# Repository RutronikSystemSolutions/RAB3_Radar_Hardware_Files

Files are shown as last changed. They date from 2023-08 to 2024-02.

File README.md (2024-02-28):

# RAB3-Radar Hardware Design Files

The RAB3-Radar is an evaluation board featuring the Infineon BGT60TR13CE6327XUMA1 and Nisshinbo NJR4652F2S1 60GHz Radars. 

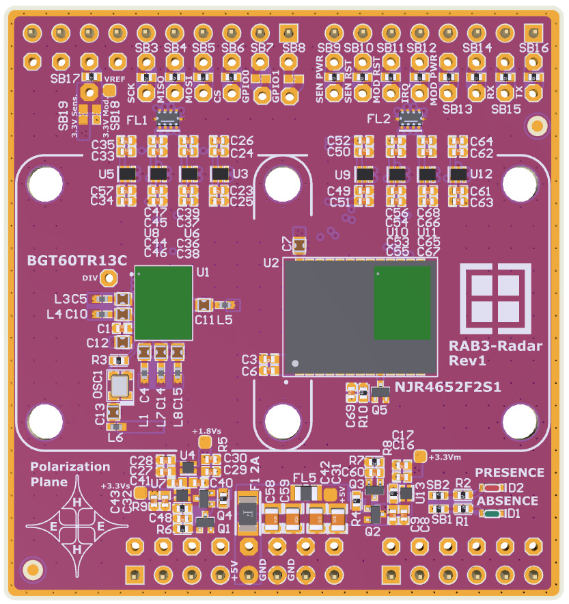
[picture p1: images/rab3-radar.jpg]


Here you may find hardware documents as follows:

- Schematics, PCB layout, and mechanical drawings
- BOM: Bill of Materials
- Assembly drawings
- Altium Designer Project
- Gerber Files

## Legal Disclaimer

The evaluation board including the software is for testing purposes only and, because it has limited functions and limited resilience, is not suitable for permanent use under real conditions. If the evaluation board is nevertheless used under real conditions, this is done at one’s responsibility; any liability of Rutronik is insofar excluded. 

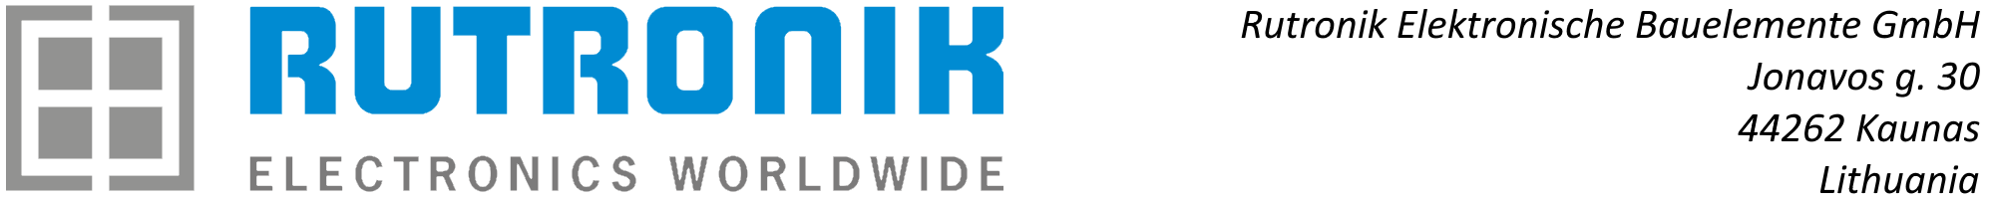
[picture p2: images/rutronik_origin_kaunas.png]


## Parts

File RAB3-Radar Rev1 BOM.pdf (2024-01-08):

Part Description | Specification | Value | Designator | Footprint | Quantity | Manufacturer | Manufacturer Part No. | Supplier | Supplier part number
Ceramic Capacitor | X5R, 6.3V, 10% | 1uF | C1, C8, C27, C40 | C0402 | 4 | Samsung EM | CL05A105KQ5NNNC | Rutronik | KKK18264
Ceramic Capacitor | X5R, 6.3V, 20% | 10uF | C3, C16, C29, C32 | C0402 | 4 | Samsung EM | CL05A106MQ5NUNC | Rutronik | KKS2215
Feed Through Capacitor | 4V, 2A, 20% | 22uF | C4, C5, C7, C10, C11, C12, C13, C14, C15 | NFMJMPC226R0G3D | 9 | muRata | NFMJMPC226R0G3D | Rutronik | NFMJMPC226R0G3D
Ceramic Capacitor | NP0, 50V, 5% | 33pF | C6, C9, C17, C23, C24, C28, C30, C33, C36, C37, C41, C43, C44, C45, C48, C49, C50, C53, C54, C57, C60, C61, C62, C65, C66, C69 | C0402 | 26 | AVX | 04025A330JAT2A | Rutronik | KKK13594
Ceramic Capacitor | X7R, 50V, 10% | 100nF | C25, C26, C34, C35, C38, C39, C46, C47, C51, C52, C55, C56, C63, C64, C67, C68 | C0402 | 16 | Yageo | CC0402KRX7R9BB104 | Rutronik | KKK23619
Ceramic Capacitor | X7R, 50V, 10% | 1uF | C31 | C0805 | 1 | Yageo | CC0805KKX7R9BB105 | Rutronik | KKK20733
Ceramic Capacitor | X7R, 25V, 20% | 22uF | C42 | C0805 | 1 | Samsung EM | CL21A226MAYNNNE | Rutronik | KKK24951
Ceramic Capacitor | X7R, 50V, 10% | 10nF | C58 | C0805 | 1 | Yageo | CC0805KRX7R9BB103 | Rutronik | KKK13596
Ceramic Capacitor | X7R, 50V, 10% | 100nF | C59 | C0805 | 1 | Yageo | CC0805KRX7R9BB104 | Rutronik | KKK15320
TOPLED® E1608 | GREEN, 20mA | KGDELLS1.22-JGKH-24-0-2-S | D1 | KG_DELLS_GREEN | 1 | OSRAM | KGDELLS1.22-JGKH-24-0-2-S | Rutronik | LEDATV1791
TOPLED® E1608 | RED, 20mA | KSDELLS1.22-JHKI-1-0-2-S | D2 | KS_DELLS_RED | 1 | OSRAM | KSDELLS1.22-JHKI-1-0-2-S | Rutronik | LEDATV2344
High I²t Chip fuse | 32V, 2A | CC12H2A-TR | F1 | FUSE1206 | 1 | EATON | CC12H2A-TR | Rutronik | FUSE10755
EMI Suppression LC Filter | 50MHz . 20mA | NFA21SL806X1A48L | FL1, FL2 | NFA21SL506X1A48L | 2 | muRata | NFA21SL806X1A48L | Rutronik | FE3998
Ferrite Bead | 1K@100MHz, 1.5A | MPZ2012S102AT000 | FL5 | Inductor_BKPA00201210 | 1 | TDK Corporation | MPZ2012S102AT000 | Rutronik | FE2928
Ferrite Bead | 600Ohm, 0.23A | BLM15PX601SN1D | L1, L3, L4, L5, L6, L7, L8 | L0402 | 7 | muRata | BLM15PX601SN1D | Rutronik | FE4904
Clock Oscillator | 80 MHz, ±50ppm | 80 MHz | OSC1 | OSC2016 | 1 | Kyocera AVX | KC2016K80.0000C1GE00 | Rutronik | KC2016K80.0000C1GE00
Arduino Connector | 10 pos. 2,54mm | SL 20 THR 124 10 Z | P1 | HDR1X10_ARDUINO | 1 | Fischer Elektronik | SL 20 THR 124 10 Z | Rutronik | SL 20 THR 124 10 Z
Arduino Connector | 8 pos. 2,54mm | SL 20 THR 124 8 Z | P3, P5 | HDR1X8_ARDUINO | 2 | Fischer Elektronik | SL 20 THR 124 8 Z | Rutronik | SL 20 THR 124 8 Z
Arduino Connector | 6 pos. 2,54mm | SL 20 THR 124 6 Z | P4 | HDR1X6_ARDUINO | 1 | Fischer Elektronik | SL 20 THR 124 6 Z | Rutronik | SL 20 THR 124 6 Z
N-Channel MOSFET | 20V, 0.63A | DMG1012T-7 | Q1, Q3, Q5 | SOT-523_custom | 3 | Diodes Inc. | DMG1012T-7 | Rutronik | TMOSS6623
P-Channel MOSFET | -20V, -0.6A | PJE8403_R1_00001 | Q2, Q4 | SOT-523_custom | 2 | PANJIT | PJE8403_R1_00001 | Rutronik | TMOS2833
Thick Film Resistor | 5% 0,063W | 220R | R1, R2 | R0402 | 2 | Yageo | RC0402JR-13220RL | Rutronik | WRC54705
Thick Film Resistor | 5% 0,063W | 150R | R3 | R0402 | 1 | Yageo | RC0402JR-07150RL | Rutronik | WRC33815
Thick Film Resistor | 1% 0,063W | 49.9K | R4, R5, R6, R7, R8, R9, R10 | R0402 | 7 | Yageo | RC0402FR-0749K9L | Rutronik | WRC34049
Thick Film Resistor | 5% 0,063W | 0R | SB1, SB2, SB3, SB4, SB5, SB6, SB9, SB10, SB11, SB12, SB13, SB14, SB15, SB16, SB17 | SB_0402 | 15 | Yageo | RC0402JR-070RL | Rutronik | WRC34031
60 GHz Radar Sensor | 57GHz ~ 64GHz, 3.3V | BGT60TR13CE6327XUMA1 | U1 | PG-VF2BGA-40-1 | 1 | Infineon Technologies BGT60TR13CE6327XUMA1 | | Rutronik | BGT60TR13CE6327XUMA1
60GHz Smart Sensor Micro-Module | 57GHz ~ 64GHz, 5.5V | NJR4652F2S1 | U2 | NJR4652 | 1 | NISSHINBO | NJR4652F2S1 | Rutronik | NJR4652F2S1
Single Bit Voltage Level Translator | 5.5V, 1.65V | 74LVC1T45FZ4-7 | U3, U5, U6, U8, U9, U10, U11, U12 | X2-DFN1410-6 | 8 | Diodes Inc. | 74LVC1T45FZ4-7 | Rutronik | ICLOG10841
250mA High PSRR Low Noise LDO with Enable | 5.5V, 1.8V, 250mA | AP7353-18FS4-7 | U4 | X2-DFN1010-4 | 1 | Diodes Inc. | AP7353-18FS4-7 | Rutronik | AP7353-18FS4-7
150mA Ultra-Low Quiescent Current LDO with Enable | 5.5V,3.3V, 150mA | AP7354-33FS4-7 | U7, U13 | X2-DFN1010-4 | 2 | Diodes Inc. | AP7354-33FS4-7 | Rutronik | ICSPR10461

### RAB3-Radar Rev1 BOM

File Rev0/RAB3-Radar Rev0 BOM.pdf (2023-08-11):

Part Description | Specification | Value | Designator | Footprint | Quantity | Manufacturer | Manufacturer Part No. | Supplier | Supplier part number
Ceramic Capacitor | X5R, 6.3V, 10% | 1uF | C1, C5, C8, C11, C16, C17, C18, C20, C21, C22, C27, C29, C40, C42 | C0402 | 14 | Samsung EM | CL05A105KQ5NNNC | Rutronik | KKK18264
Ceramic Capacitor | NP0, 50V, 5% | 33pF | C2, C6, C23, C24, C28, C30, C33, C36, C37, C41, C43, C44, C45, C48, C49, C50, C53, C54, C57 | C0402 | 19 | AVX | 04025A330JAT2A | Rutronik | KKK13594
Ceramic Capacitor | X5R, 6.3V, 20% | 10uF | C3, C4, C7, C10, C13, C14, C15 | C0402 | 7 | Samsung EM | CL05A106MQ5NUNC | Rutronik | KKS2215
Ceramic Capacitor | X7R, 50V, 10% | 100nF | C9, C12, C25, C26, C34, C35, C38, C39, C46, C47, C51, C52, C55, C56 | C0402 | 14 | Yageo | CC0402KRX7R9BB104 | Rutronik | KKK23619
Ceramic Capacitor | X7R, 25V, 10% | 4.7nF | C19 | C0402 | 1 | KEMET | C0402C472K3RAC7867 | Rutronik | KKK26721
Niobium Oxide Capacitor | 6.3V, 20% | 47uF | C31, C32 | Case-B | 2 | AVX | NOJB476M006RWJ | Rutronik | KTA6684
TOPLED® E1608 | GREEN, 20mA | KGDELLS1.22-JGKH-24-0-2-S | D1 | KG_DELLS_GREEN | 1 | OSRAM | KGDELLS1.22-JGKH-24-0-2-S | Rutronik | LEDATV1791
TOPLED® E1608 | RED, 20mA | KSDELLS1.22-JHKI-1-0-2-S | D2 | KS_DELLS_RED | 1 | OSRAM | KSDELLS1.22-JHKI-1-0-2-S | Rutronik | LEDATV2344
High I²t Chip fuse | 32V, 2A | CC12H2A-TR | F1 | FUSE1206 | 1 | EATON | CC12H2A-TR | Rutronik | FUSE10755
Ferrite Bead | 600Ohm, 0.23A | BLM15PX601SN1D | L1, L2, L3, L4, L5, L6, L7, L8 | L0402 | 8 | muRata | BLM15PX601SN1D | Rutronik | FE4904
Clock Oscillator | 80 MHz, ±20ppm | 80 MHz | OSC1 | OSC2016 | 1 | Kyocera AVX | KC2016Z80.0000C1KX00 | Rutronik | KC2016Z80.0000C1KX00
Arduino Connector | 10 pos. 2,54mm | AW140-EG-G10B | P1 | HDR1X10_ARDUINO | 1 | ASSMANN WSW | AW140-EG-G10B | Rutronik | AW140-EG-G10B
Arduino Connector | 8 pos. 2,54mm | AW140-EG-G08B | P3, P5 | HDR1X8_ARDUINO | 2 | ASSMANN WSW | AW140-EG-G08B | Rutronik | AW140-EG-G08B
Arduino Connector | 6 pos. 2,54mm | AW140-EG-G06B | P4 | HDR1X6_ARDUINO | 1 | ASSMANN WSW | AW140-EG-G06B | Rutronik | AW140-EG-G06B
N-Channel MOSFET | 20V, 0.63A | DMG1012T-7 | Q1 | SOT-523_custom | 1 | Diodes Inc. | DMG1012T-7 | Rutronik | TMOSS6623
Thick Film Resistor | 5% 0,063W | 220R | R1, R2 | R0402 | 2 | Yageo | RC0402JR-13220RL | Rutronik | WRC54705
Thick Film Resistor | 5% 0,063W | 150R | R3 | R0402 | 1 | Yageo | RC0402JR-07150RL | Rutronik | WRC33815
Thick Film Resistor | 1% 0,063W | 49.9K | R5, R6 | R0402 | 2 | Yageo | RC0402FR-0749K9L | Rutronik | WRC34049
Thick Film Resistor | 5% 0,063W | 0R | SB1, SB2, SB3, SB4, SB5, SB6, SB7, SB8, SB9, SB10, SB11, SB12, SB13, SB14, SB15, SB16 | SB_0402 | 16 | Yageo | RC0402JR-070RL | Rutronik | WRC34031
60 GHz Radar Sensor | 57GHz ~ 64GHz, 3.3V | BGT60TR13CE6327XUMA1 | U1 | PG-VF2BGA-40-1 | 1 | Infineon Technologies | BGT60TR13CE6327XUMA1 | Rutronik | BGT60TR13CE6327XUMA1
60GHz Smart Sensor Micro-Module | 57GHz ~ 64GHz, 5.5V | NJR4652F2S1 | U2 | NJR4652 | 1 | NISSHINBO | NJR4652F2S1 | Rutronik | NJR4652F2S1
Single Bit Voltage Level Translator | 3.6V, 1.2V | 74AVC1T45FZ4-7 | U3, U5, U6, U8, U9, U10 | X2-DFN1410-6 | 6 | Diodes Inc. | 74AVC1T45FZ4-7 | Rutronik | 74AVC1T45FZ4-7
250mA High PSRR Low Noise LDO with Enable | 5.5V, 1.8V, 250mA | AP7353-18FS4-7 | U4 | X2-DFN1010-4 | 1 | Diodes Inc. | AP7353-18FS4-7 | Rutronik | AP7353-18FS4-7
150mA Ultra-Low Quiescent Current LDO with Enable | 5.5V,3.3V, 150mA | AP7354-33FS4-7 | U7 | X2-DFN1010-4 | 1 | Diodes Inc. | AP7354-33FS4-7 | Rutronik | ICSPR10461

## RAB3-Radar Rev0 BOM

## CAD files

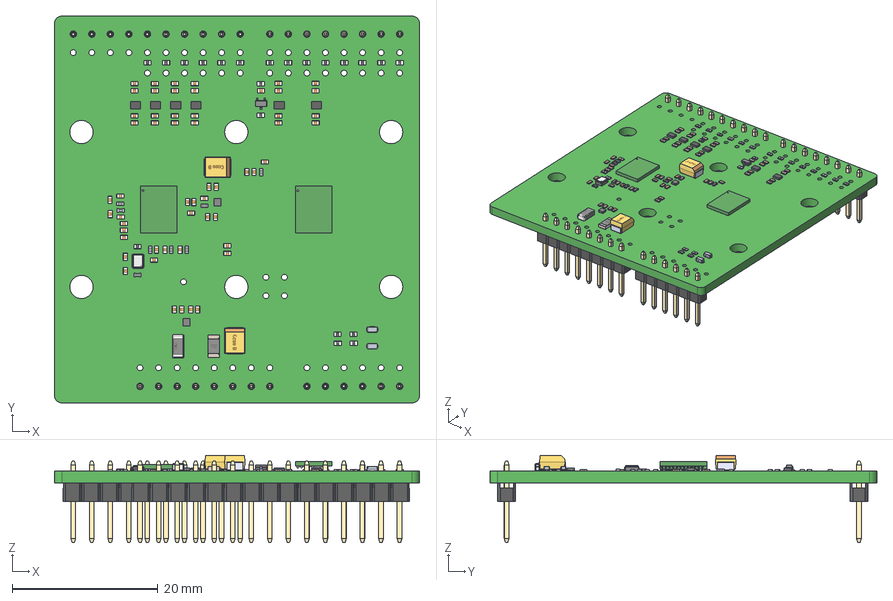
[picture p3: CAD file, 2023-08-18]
Rev0/RAB3-Radar Step Model.step
50.0 x 53.0 x 12.0 mm
Extruded x 6
LDF x 2
PG-VF2BGA-40-1 x 2
User_Library-SOT-523
pin_header_aw140-eg-g08d x 2
pin_header_aw140-eg-g06d
pin_header_aw140-eg-g10d
2016_osc
inductor_0402 x 8
User_Library-SF-1206F
KG_DELMS1_22_20160429_geometry x 2
SW3dPS-0402_SMD_Capacitor x 55
User_Library-Tantalum_Capacitor_Case_B_Tantalum_case_B_part1 x 2
User_Library-Tantalum_Capacitor_Case_B_Tantalum_case_B_part2 x 4

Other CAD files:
RAB3-Radar Parasolid Model.x_t

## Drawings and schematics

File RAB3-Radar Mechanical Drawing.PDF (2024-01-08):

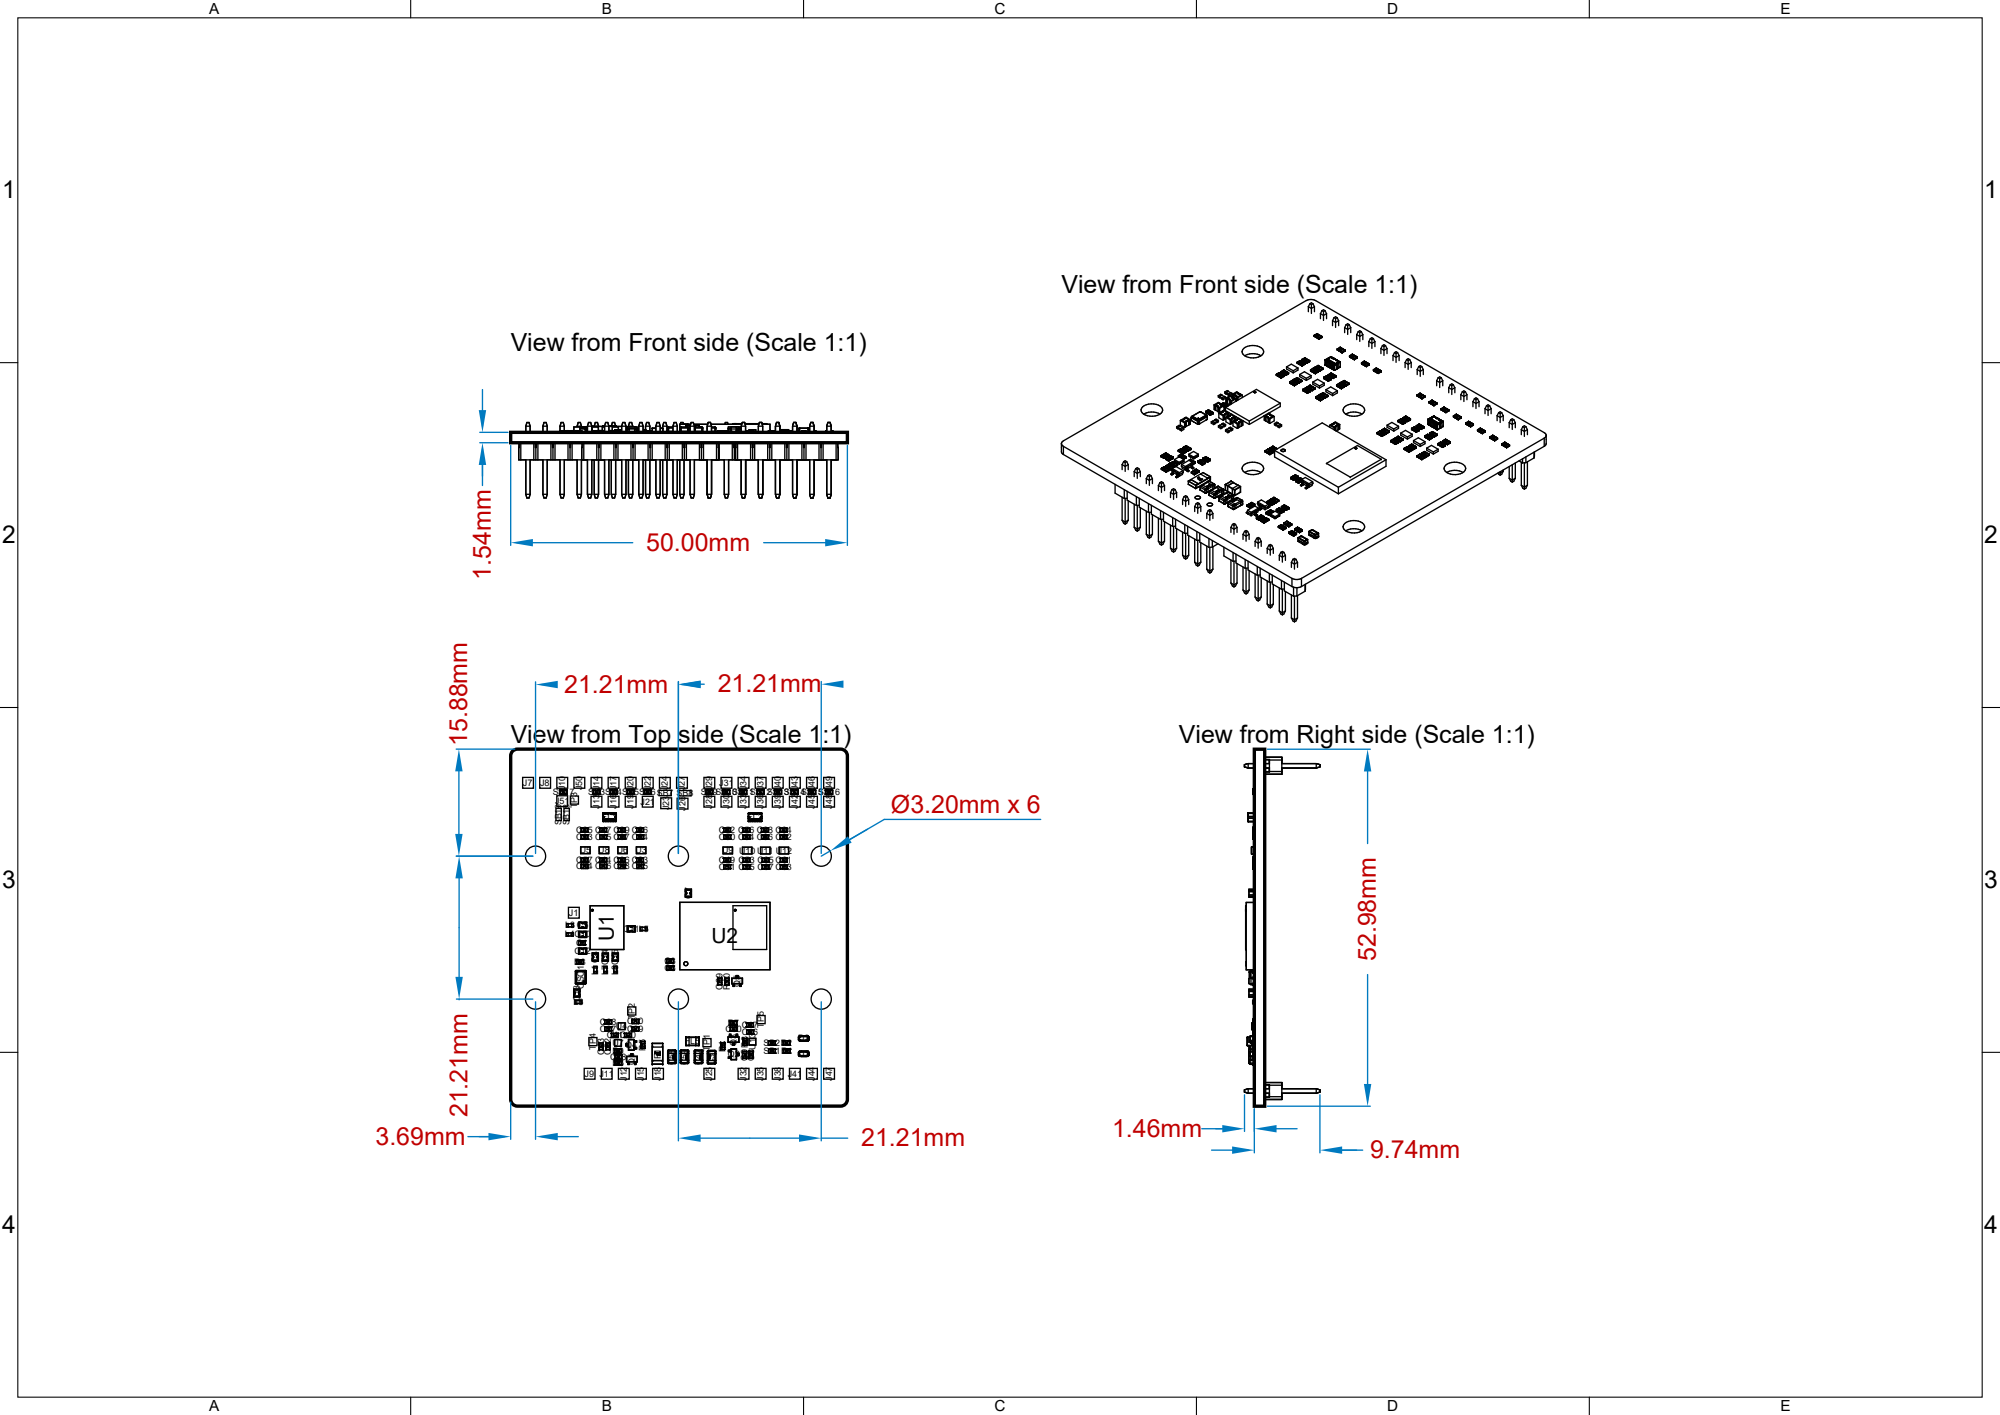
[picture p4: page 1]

View from Front side (Scale 1:1) 52.98mm

View from Front side (Scale 1:1)

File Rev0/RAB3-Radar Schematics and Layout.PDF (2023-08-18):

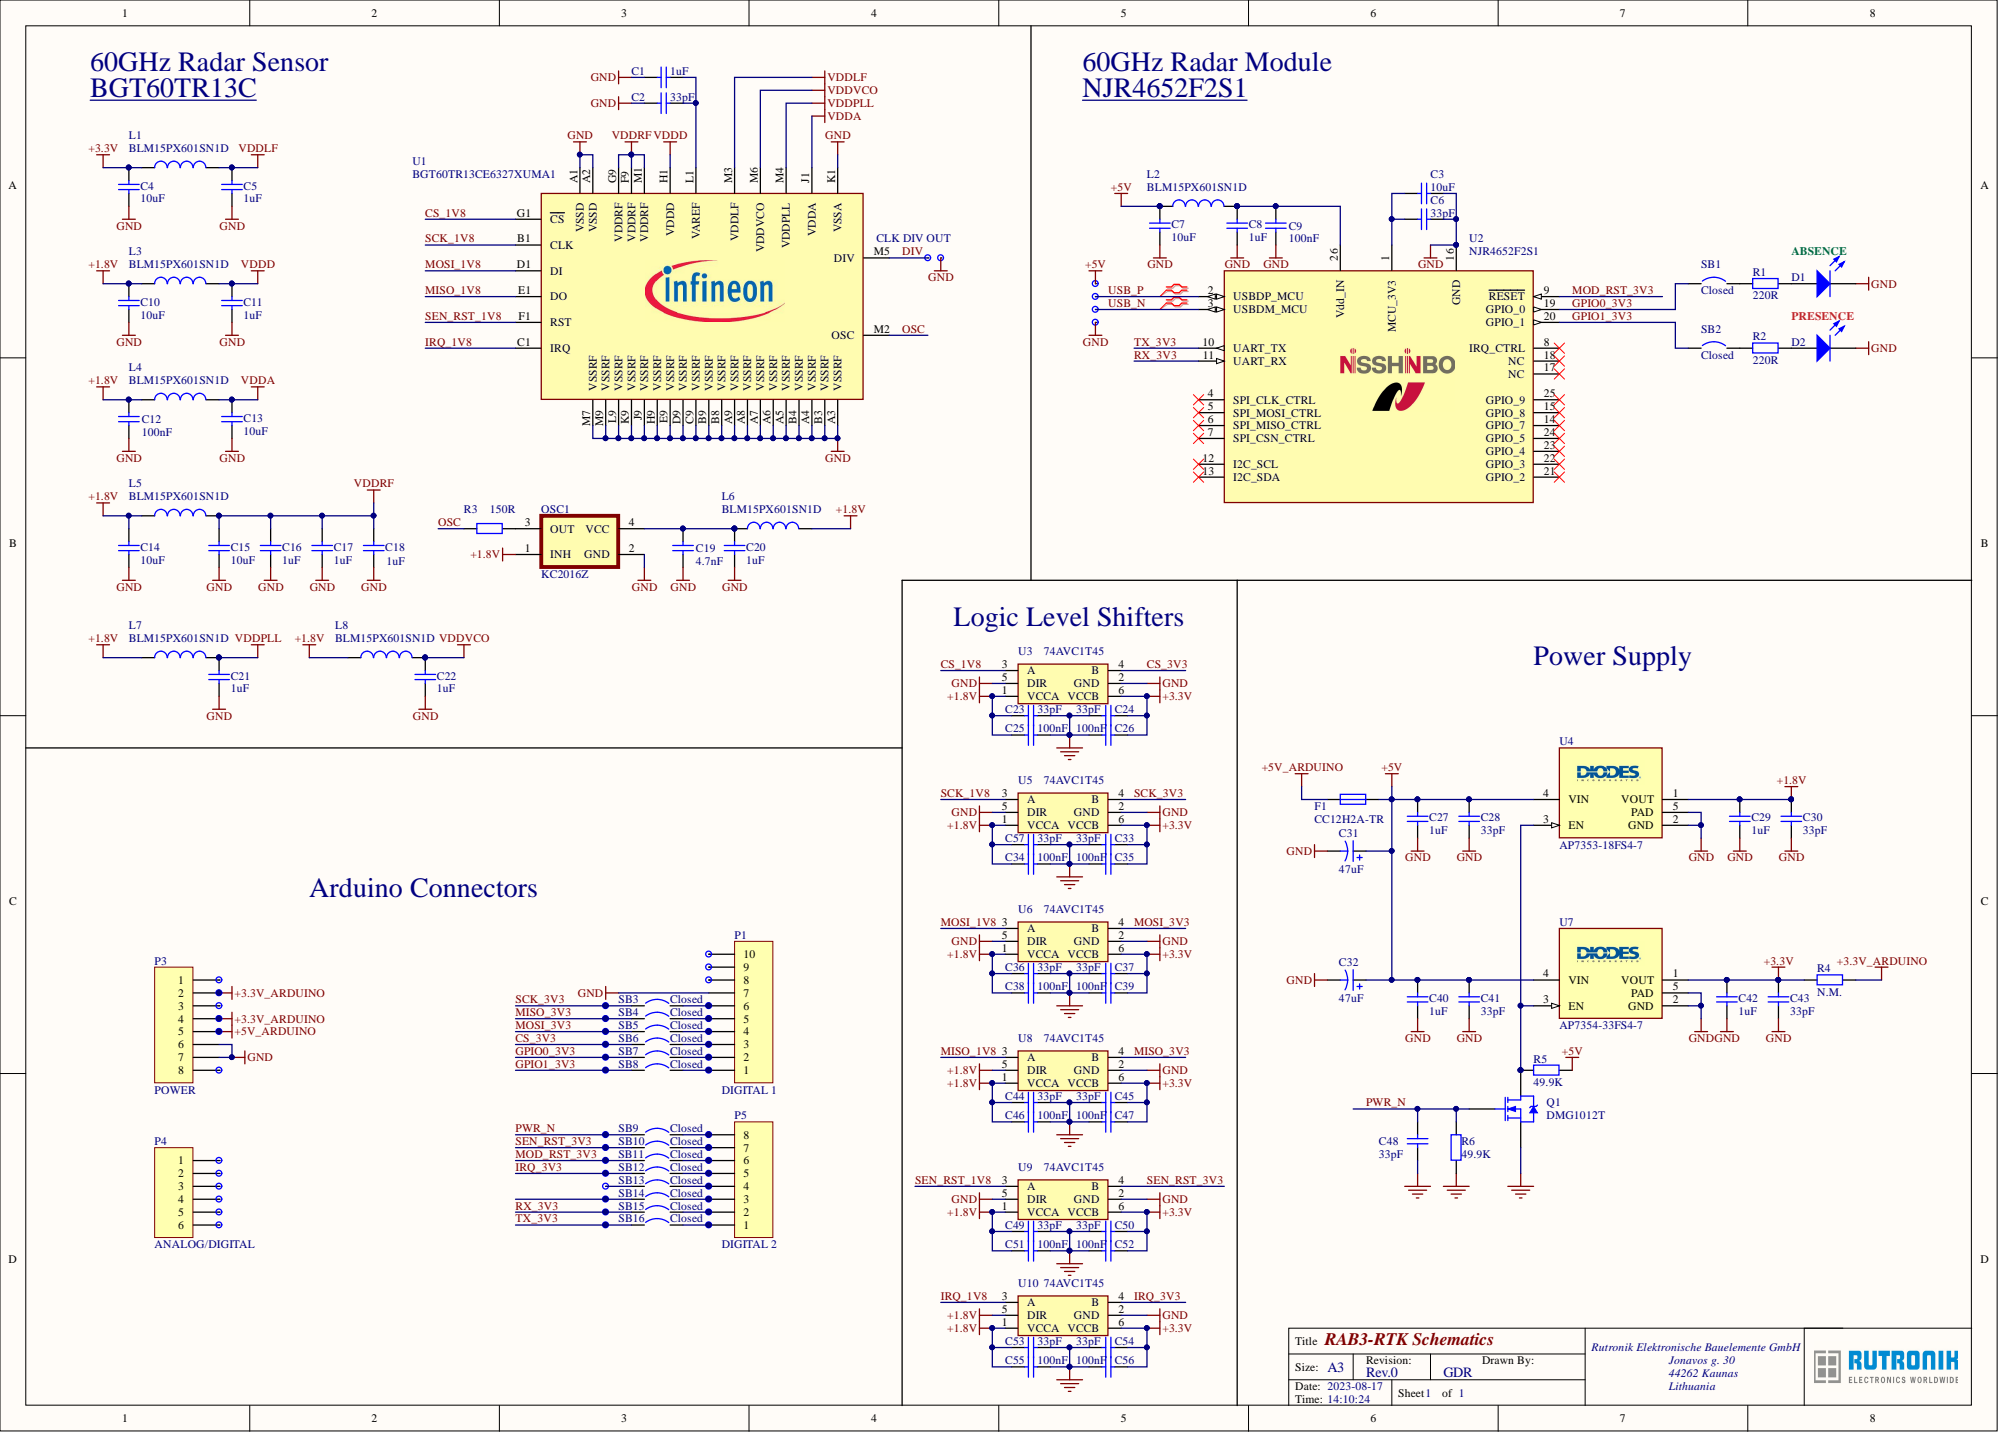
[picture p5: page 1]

VSSRF H9 VSSRF J9 VSSRF K9 VSSRF L9 VSSRF M9

VSSRF A5 VSSRF A6 VSSRF A7 VSSRF A8 VSSRF A9

Title RAB3-RTK Schematics | Rutronik Elektronische Bauelemente GmbH Jonavos g. 30 44262 Kaunas

A3 Size: | Revision: | Drawn By: GDR

Date: 14:10:24 | Sheet 1 of Time: | Lithuania 1

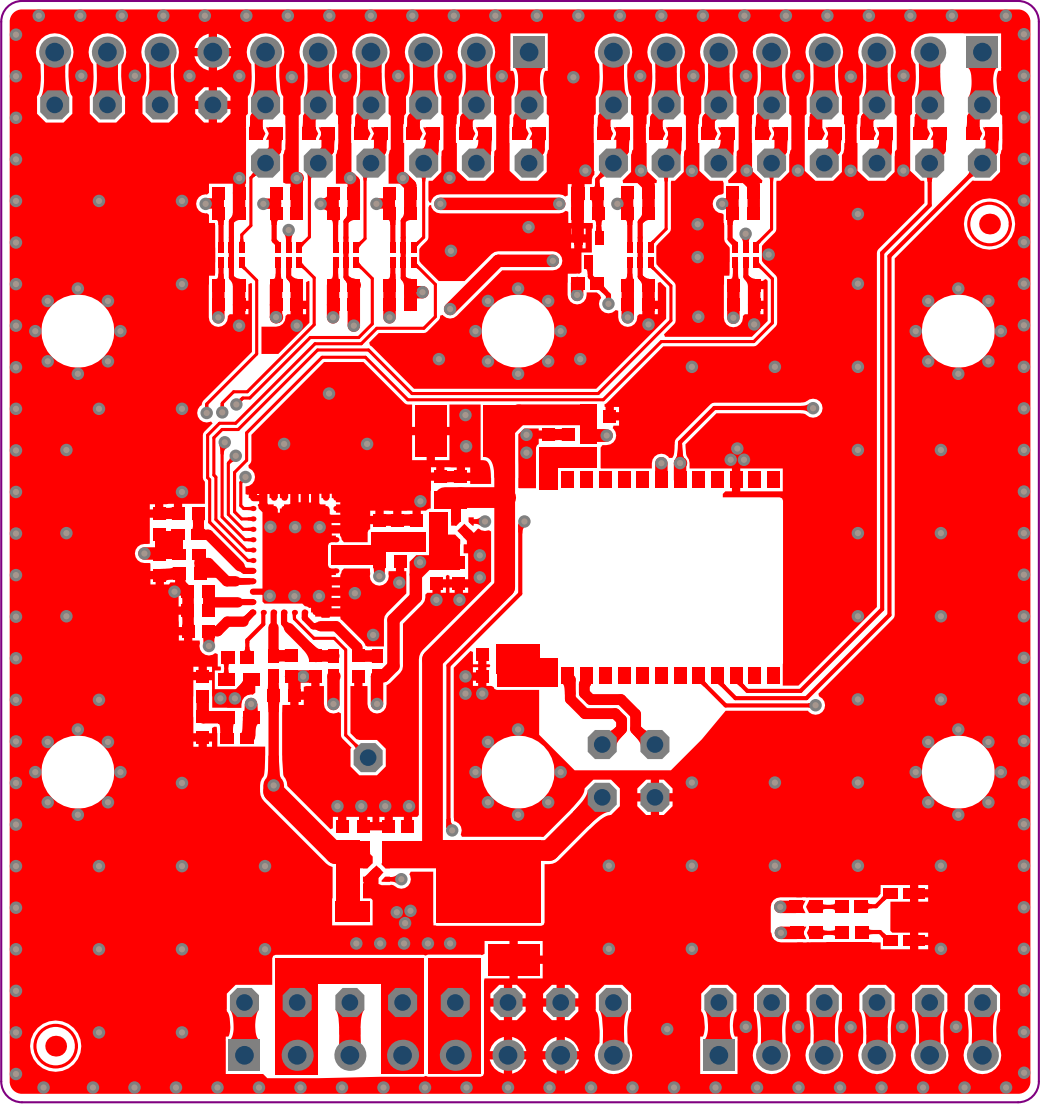
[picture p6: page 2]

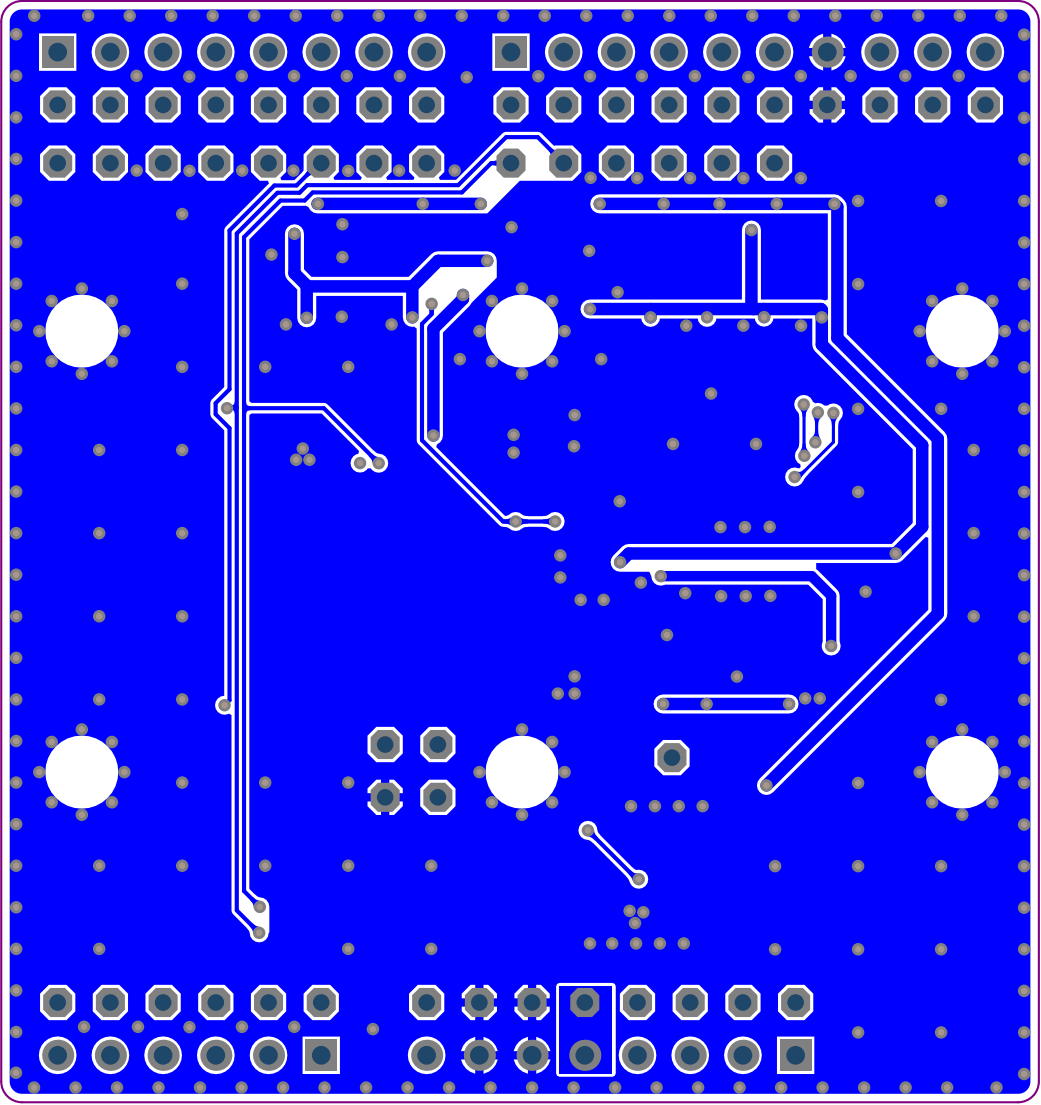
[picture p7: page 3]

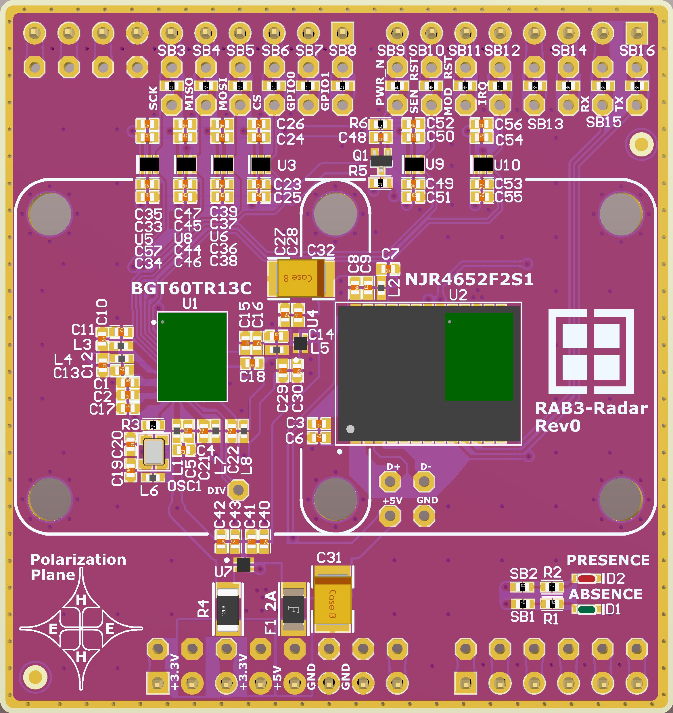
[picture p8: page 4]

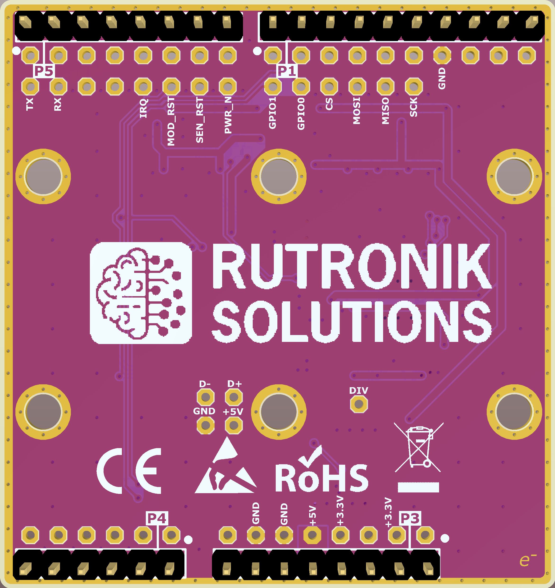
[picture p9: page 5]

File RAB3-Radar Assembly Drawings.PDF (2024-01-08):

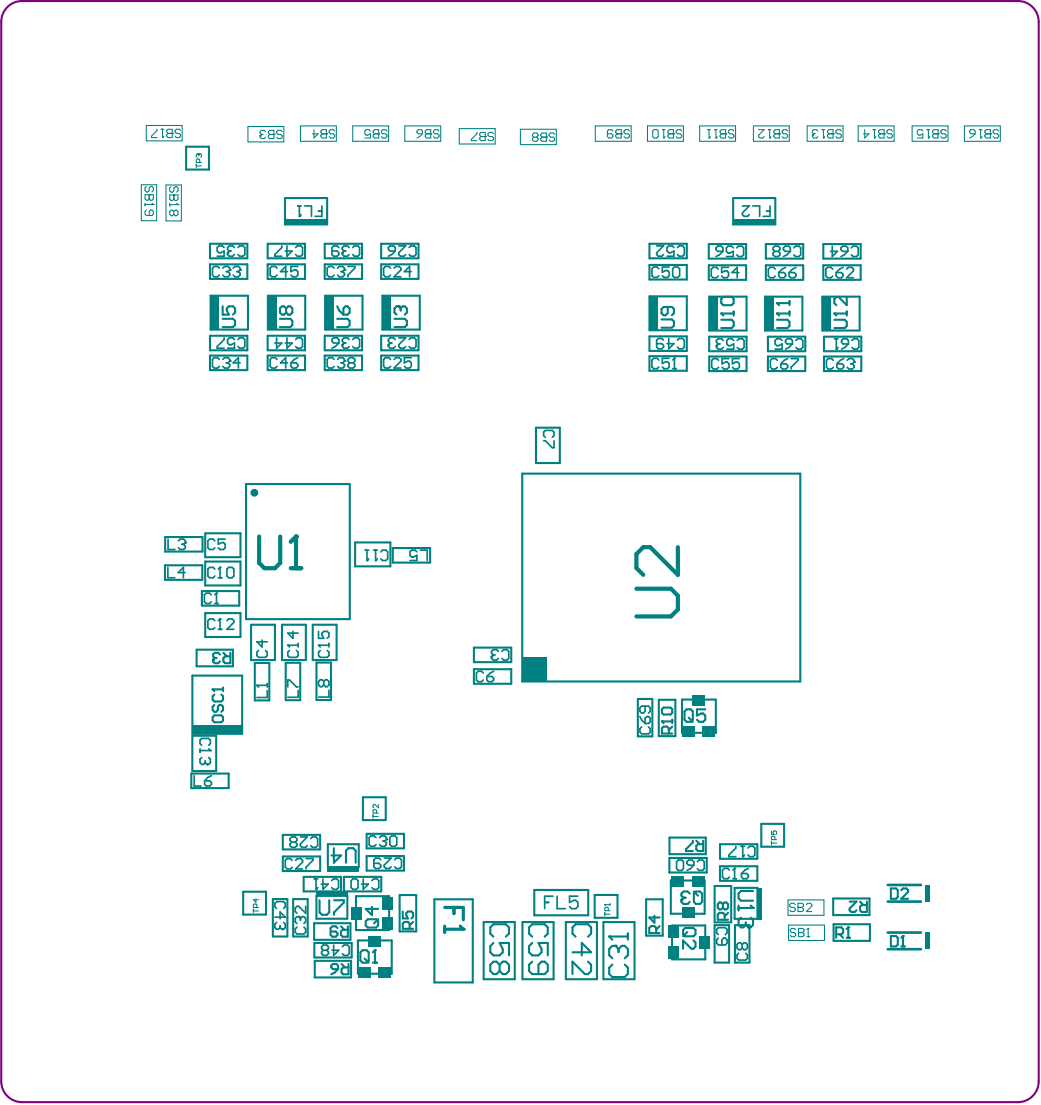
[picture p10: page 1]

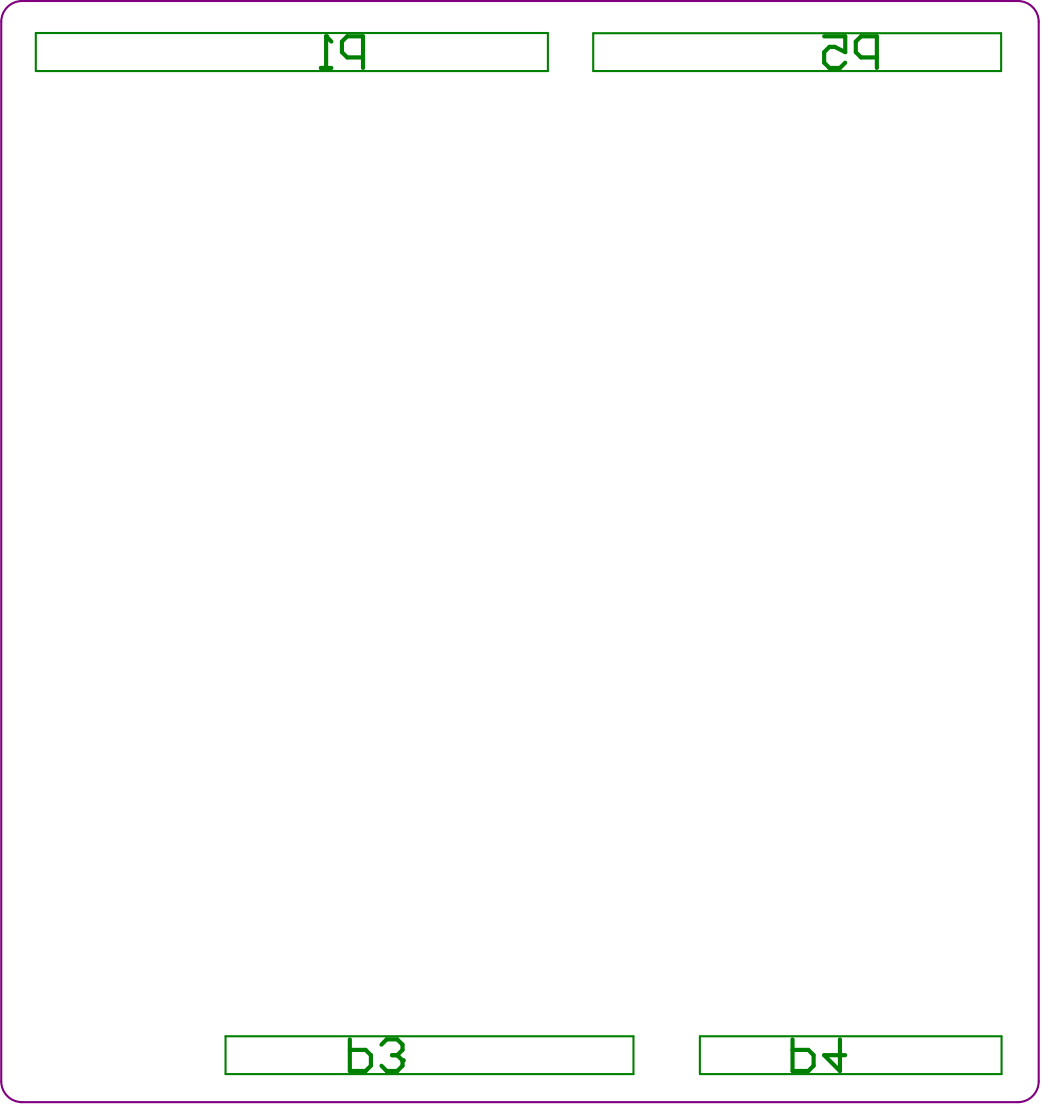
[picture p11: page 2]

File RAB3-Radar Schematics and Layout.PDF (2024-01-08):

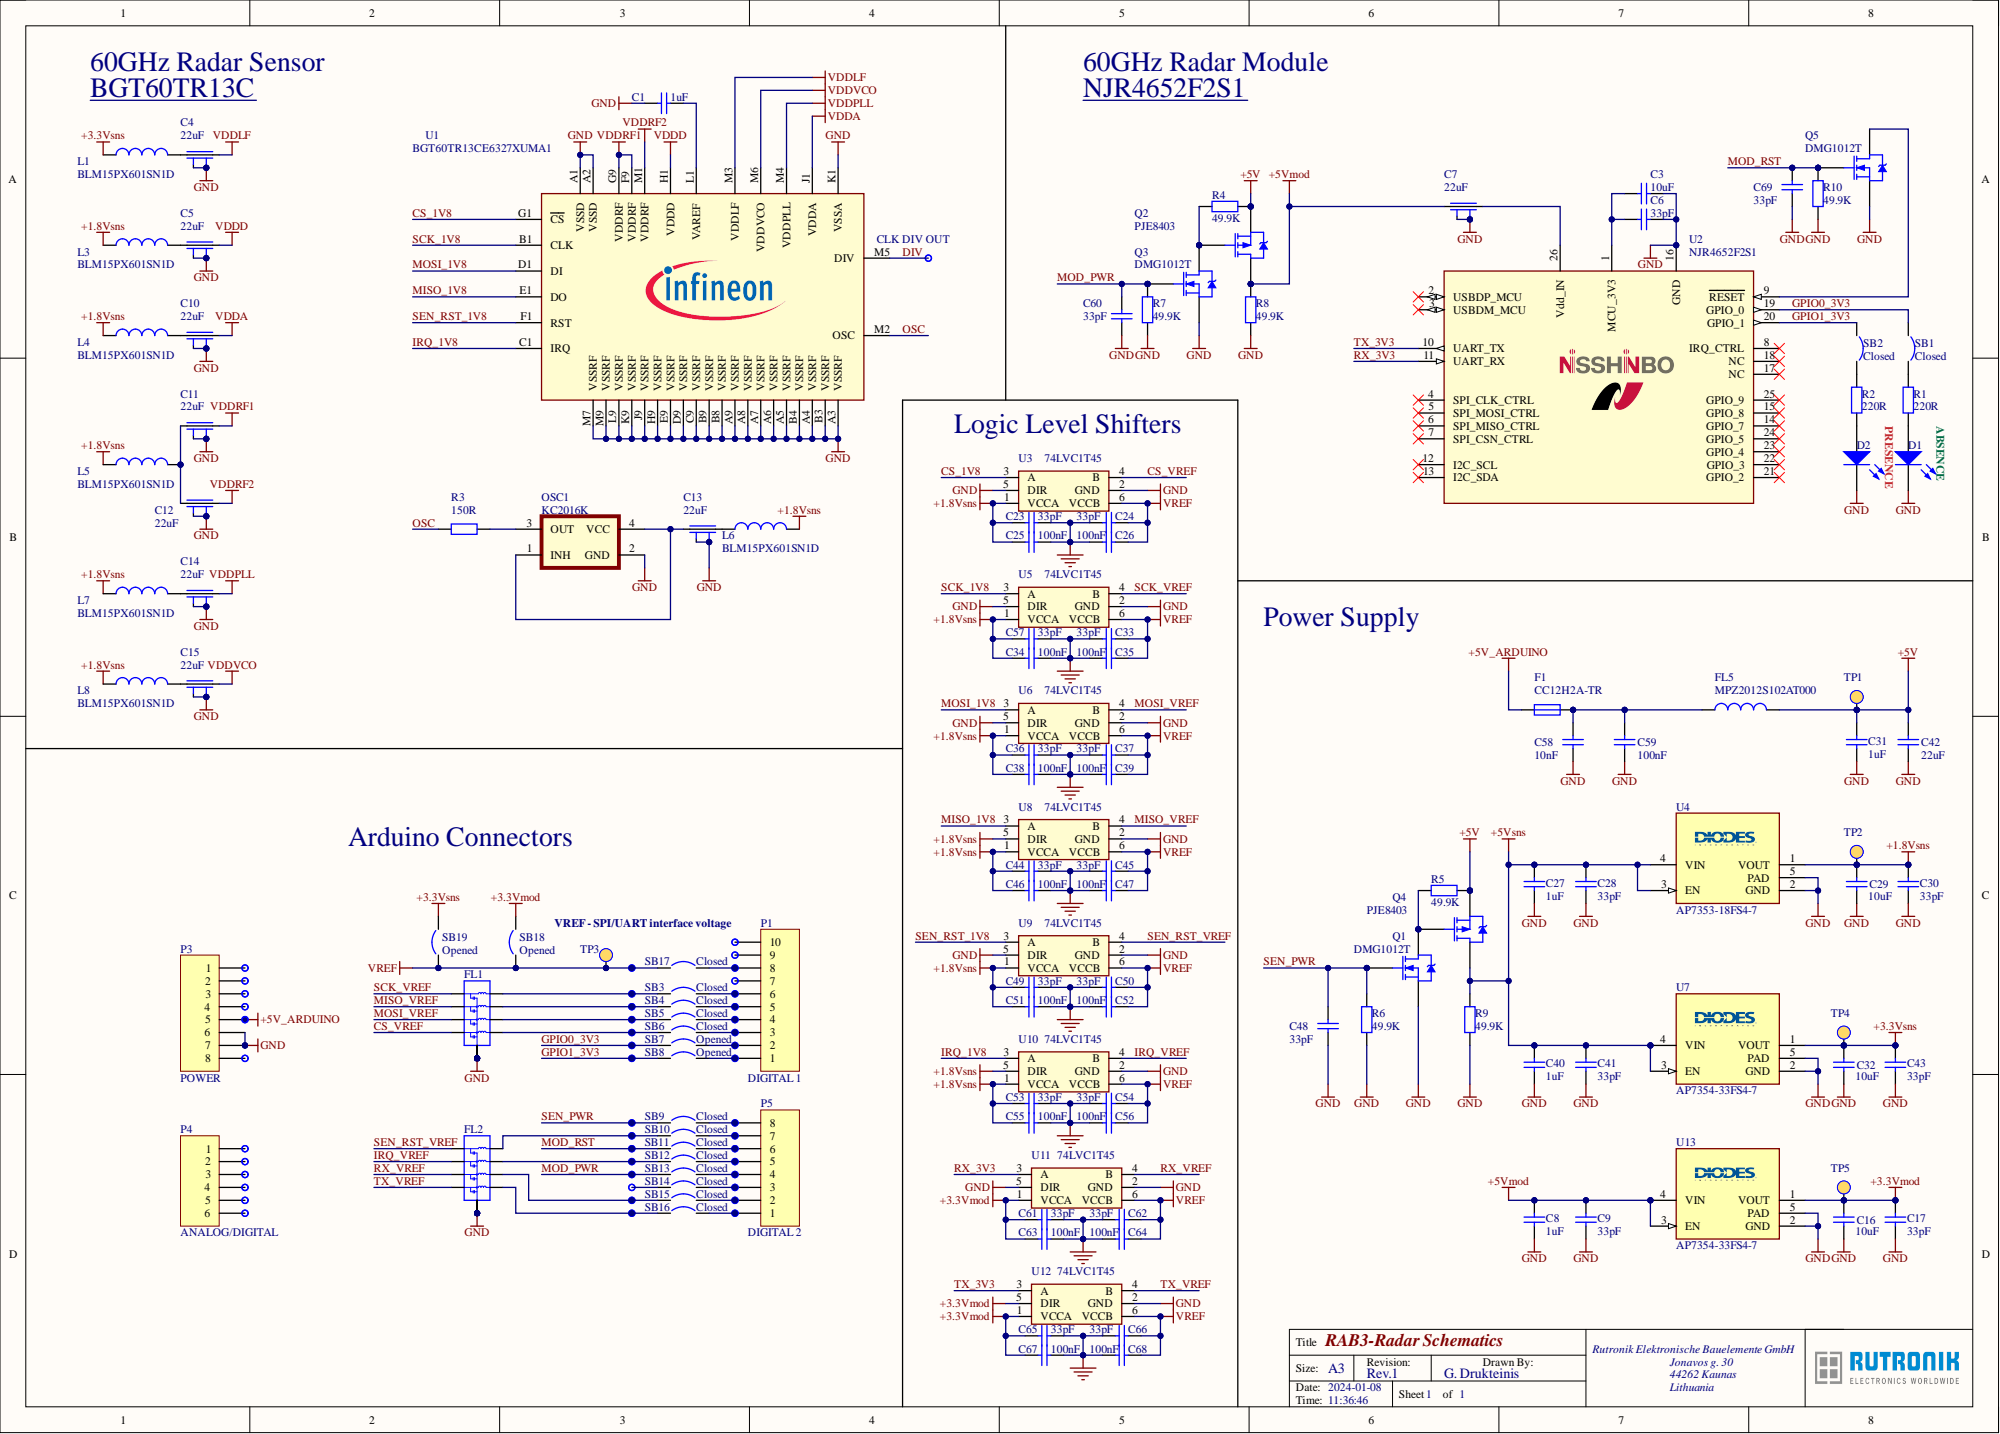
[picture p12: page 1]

VSSRF H9 VSSRF J9 VSSRF K9 VSSRF L9 VSSRF M9

VSSRF A5 VSSRF A6 VSSRF A7 VSSRF A8 VSSRF A9

Size : A 3 | Rev i s i o n : Re v . 1 | Draw n By : G. Dru ktein i s

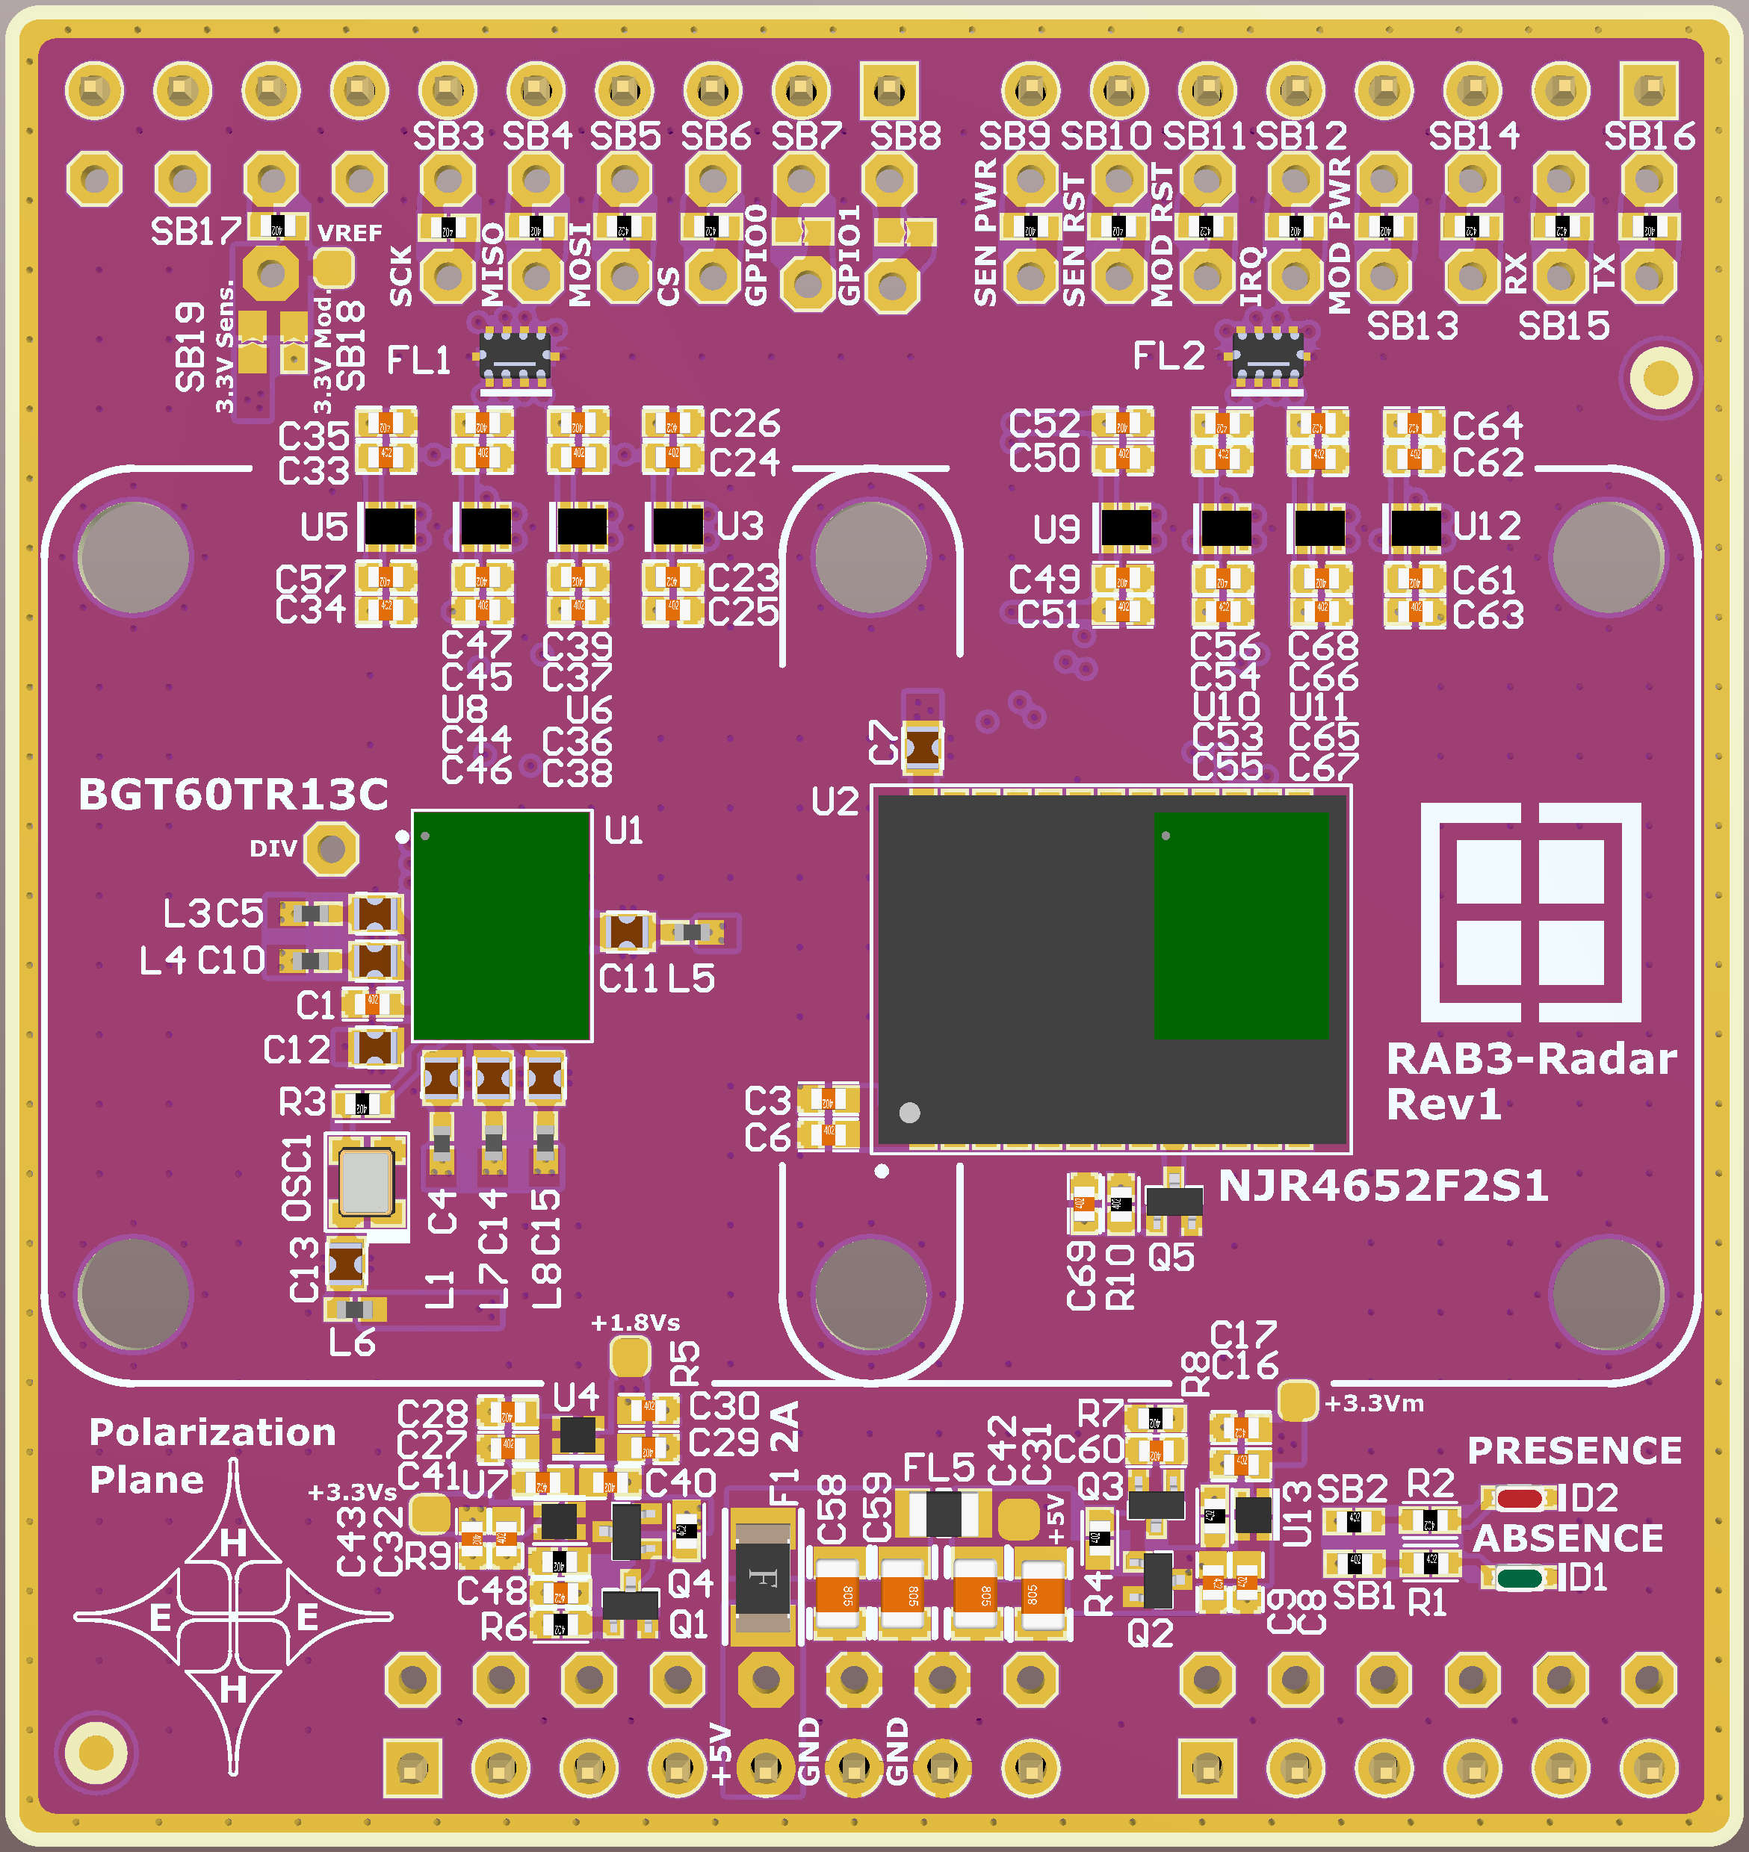
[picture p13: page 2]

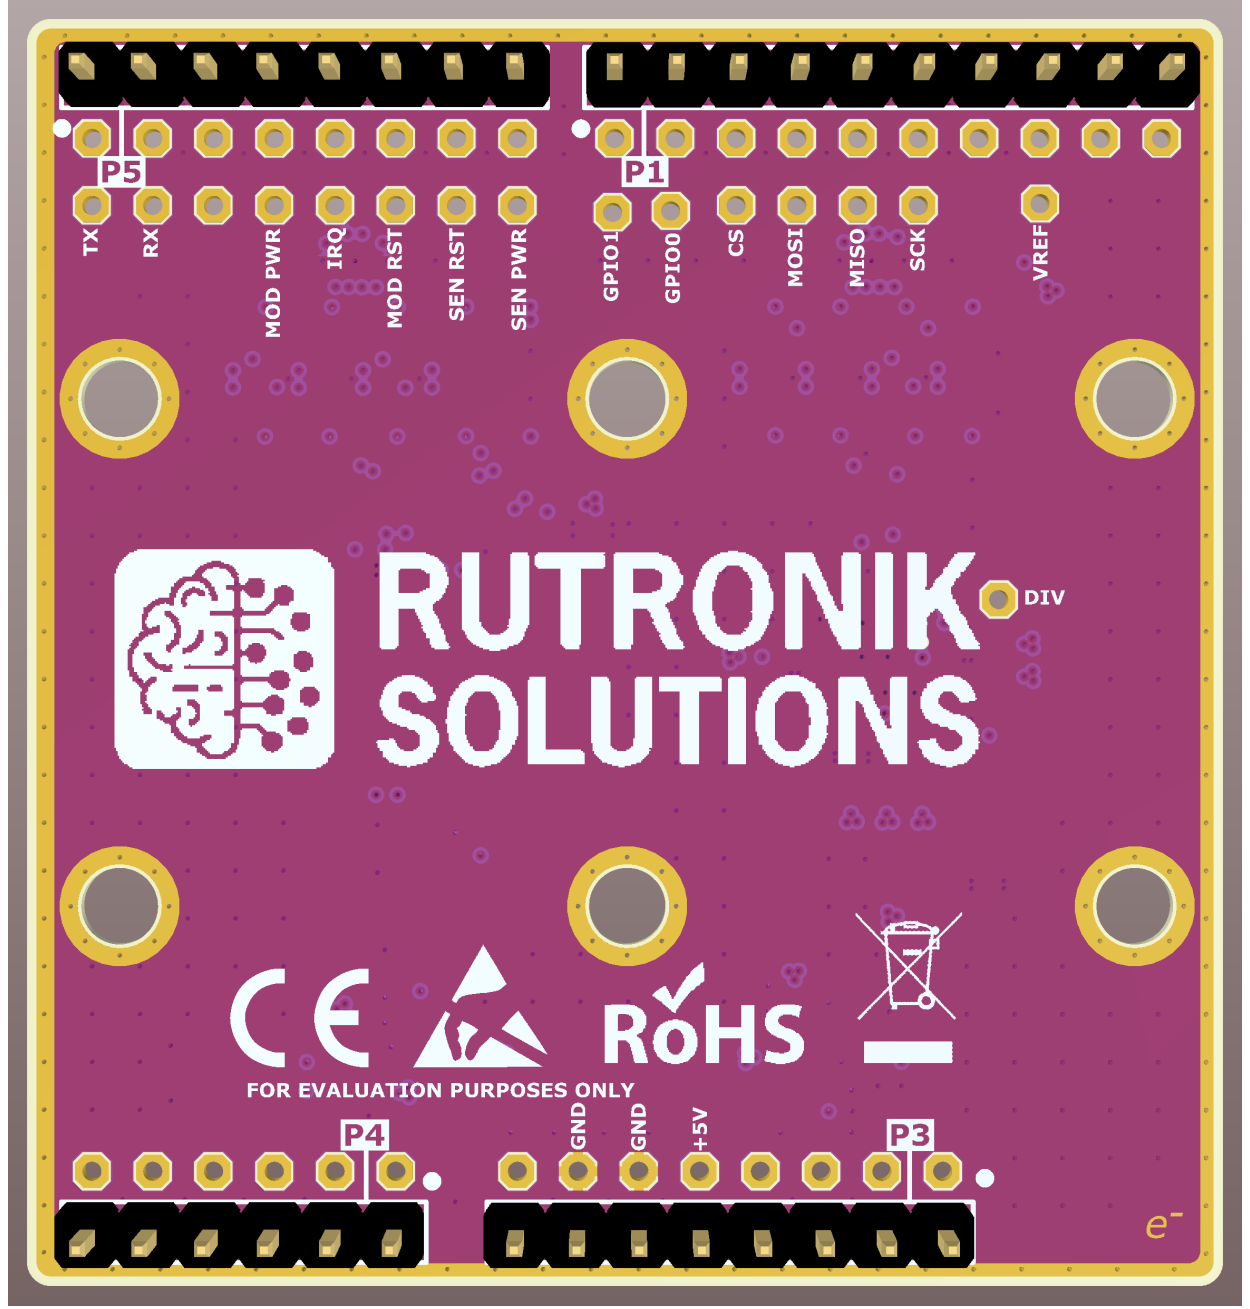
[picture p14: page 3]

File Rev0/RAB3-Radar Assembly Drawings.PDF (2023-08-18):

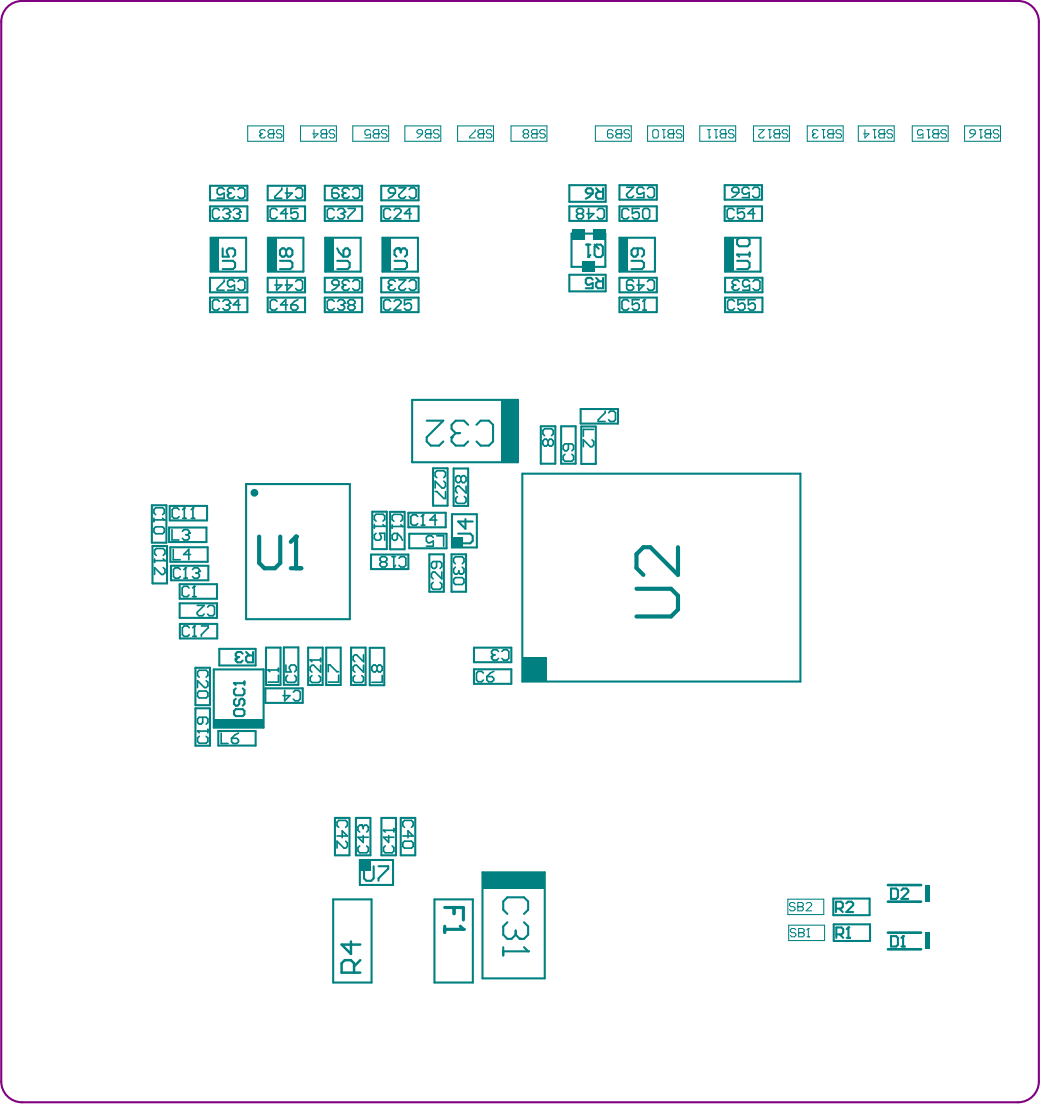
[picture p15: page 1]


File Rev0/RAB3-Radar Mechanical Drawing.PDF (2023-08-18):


View from Front side (Scale 1:1)

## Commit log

2023-08-11 Initial commit.
    [RAB3-Radar Rev0 BOM.xls]
2023-08-18 Rev0 release.
    [RAB3-Radar Step Model.step]
2023-10-03 Rev1 updates.
    [RAB3-Radar Rev0 BOM.xls]
2023-12-06 Rev0 legacy
    [RAB3-Radar Rev0 BOM.xls, RAB3-Radar Step Model.step]
2024-01-08 Rev1 production updates.
    [RAB3-Radar Rev1 BOM.xls]
2024-05-22 step and parasolid models added
    [RAB3-Radar Parasolid Model.x_t]
